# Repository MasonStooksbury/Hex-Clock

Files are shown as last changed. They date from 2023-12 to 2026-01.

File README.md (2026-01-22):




# Hex Clock | KiCad 9.0

From the mind of my good friend and inventor Johnathan Wood comes: the *Hex Clock*. A novel timepiece combining two of his favorite things: technology and hexagons. The Hex Clock uses two hexagons to represent sexigesimal, 24-hour time using two 6-bit binary numbers wrapped around hexagons. Let's see a picture that will hopefully make more sense. (And yes, the left-most bit of the hours hex will never be illuminated except during animations)

<br>

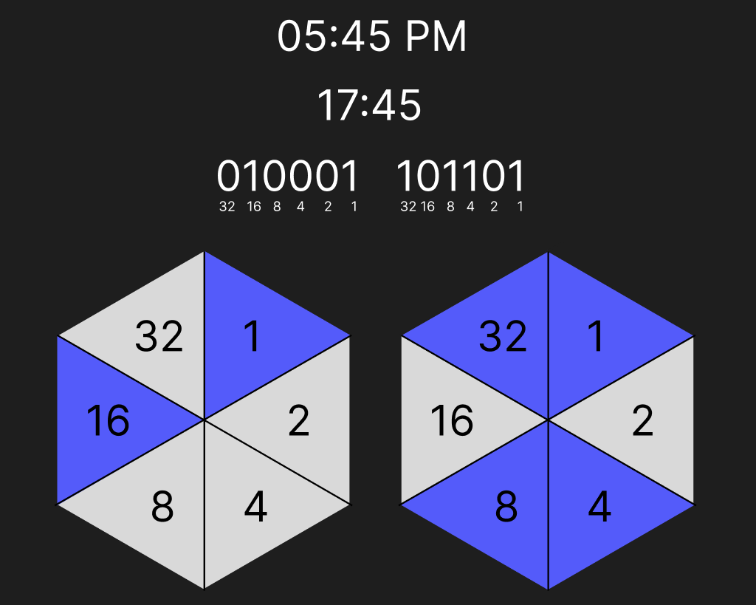
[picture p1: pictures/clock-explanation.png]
Visual description of how the clock works


<br><br><br>

# Pre-setup Instructions
### Download these things (if you don't already have them)
- Download VSCode: [link](https://code.visualstudio.com/download)
- Install VSCode Extension `MicroPico` by paulober
- Download firmware for RaspberryPi PicoW (if you haven't already done this): [latest](https://rpf.io/pico-w-firmware)
- Download/Clone the code from this repo

<br><br><br>

# Developer Setup
- Open just the `PicoWCode` folder in VSCode; it should look something like this:
  - This is really important for a later step. Doing this wrong could have weird effects or just not work
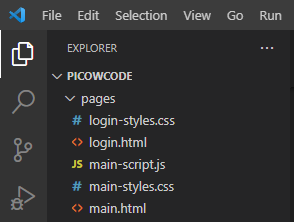
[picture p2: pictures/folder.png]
How the file explorer should look in VSCode
  - 
- Plug in your PicoW (`pico` from now on)
- Under the `View` tab, click on `Command Palette...` or do `Ctrl + Shift + P` if that shortcut is enabled
- Click `MicroPico: Connect` to attempt a connection to the pico
- Once connected, you will see options appear in the footer bar of VSCode (you'll use these mostly):
  - What the footer options look like
- If all is good, you should see that checkmark with "Pico Connected" next to it
  - If this doesn't work, try replugging it, getting a different cable, or trying a different USB port
- Finally, open up the `test.py` file and make sure that you are on that tab (when we hit the `Run` footer button, MicroPico will attempt to run whatever tab we currently have focused)
- Click the `Run` footer button
- If you see "Everything is awesome!" in the terminal, then you're ready to start developing!

<br><br><br>

# Developing and Testing
### This will put all of your code onto the pico, and allow you to start testing
- Click the `All commands` footer button
- Click `MicroPico: Upload project to Pico`. This will put all of the files in the lefthand explorer onto the pico (this is why we need to open *only* the `PicoWCode` folder in VSCode)
- Once finished, it's often good to do a soft reset (no idea why, I've just noticed it help sometimes) simply click the `Reset` footer button
- Make sure that the `main.py` (or whatever `.py` file you are currently testing) is open and focused
- Click the `Run` footer button

<br>

## Quick and Dirty Testing
### If you just want to test code in a singular file (and don't really need everything else) you can simply focus the relevant file and hit the `Run` footer button. This is particularly helpful when developing new animations or random bits of code

### NOTE: If you're trying to test a file that imports another file (and you're changing both files regularly), this won't work and you'll have to follow the above instructions where you upload the code to the pico. 
  
<br><br><br>

# Connecting to the Pico and Using the Web App
### These instructions will help you connect to the Pico with your phone or other device and use the webapp that allows you to set the clock colors, change the time, or change the login credentials
- Either plug in the pico to an external power source or - if developing with VSCode open - connect the pico, open the main.py file, and click the `Run` footer button
- Once you see the `AP is active. You can now connect` message, the pico wifi access point (AP) is ready to receive connections
- Take note of the IP address listed just below this as you will need it in a moment (NOTE: In final version, this will hopefully be replaced with a domain name that you can connect to)
- On a wifi-enabled device, look for the `Hex Clock` network and connect to it (this is the default name and can be changed in the `main.py` script if desired)
- Once connected, open your web browser and type in the IP address from the previous step into the address bar
- At this point, you should see the Hex Clock login screen
- Login with these default credentials:
  - Username: `flump`
  - Password: `doople`

<br><br><br>

# Changing the Access Point SSID
- Changing the AP SSID is as simple as changing the line towards the top of `main.py`. However, the tricky part is in getting it propagate
- The steps below are about the only sure-fire way I've found to get it to work
  - Make sure the pico isn't currently running (if it is, click the `Stop` footer button to do so)
  - Click the `All commands` footer button
  - Click the `MicroPico: Delete all files from board` option
  - Click the `Reset` footer button
  - Physically unplug the pico from the computer
  - Plug the pico back in
  - Reconnect MicroPico manually or wait a second (it's usually pretty good about reconnecting automatically)
  - Click the `All commands` footer button
  - Click the `MicroPico: Upload project to Pico` option
  - Click the `Reset` footer button
  - On your wifi-enabled device that you are going to connect, go into your wifi settings and forget the network you previously attached to (this is critical as sometimes it will not show the SSID change on your device)
  - Click the `Run` footer button
  - At this point you should see the new SSID being broadcast under the available networks

<br><br><br>

# Troubleshooting
### These are some things I've run into and how to fix them
- Every now and then when you try to run `main.py` and the AP attempts to start up you might see this error: `OSError: [Errno 98] EADDRINUSE`. Follow these steps to mitigate it
  - If running, click the `Stop` footer button
  - Click the `Reset` footer button to perform a soft reset of the pico
  - Click the `Run` footer button again
  - If the above steps do not work, you can also just try click `Run` over and over again. Usually after 3-5 attempts it will work
- Sometimes when trying to hit the `Run` footer button you will see: `SyntaxError: invalid syntax`. Typically this just means that you have the wrong script focused. Make sure you are on the `main.py` script (or whatever script you're working on)

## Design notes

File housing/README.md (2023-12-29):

- Use the STL files if you just want to print the housing
- Use the STP/STEP files if you want to *modify* the housing in Fusion360 or other CAD software

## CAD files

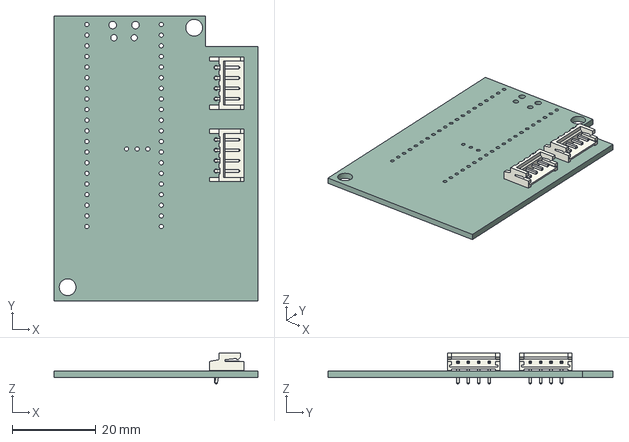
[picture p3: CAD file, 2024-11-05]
pcb/main-board/main-board.step
48.8 x 68.0 x 7.40 mm
JST_S4B_EH x 2
main-board_PCB

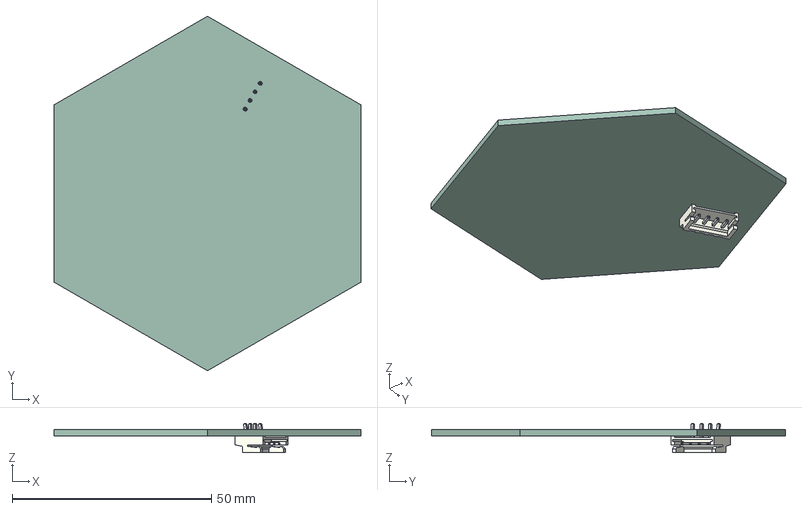
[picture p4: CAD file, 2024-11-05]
pcb/hex-board/hex-board.step
77.1 x 89.0 x 7.40 mm
JST_S4B_EH
hex-board_PCB

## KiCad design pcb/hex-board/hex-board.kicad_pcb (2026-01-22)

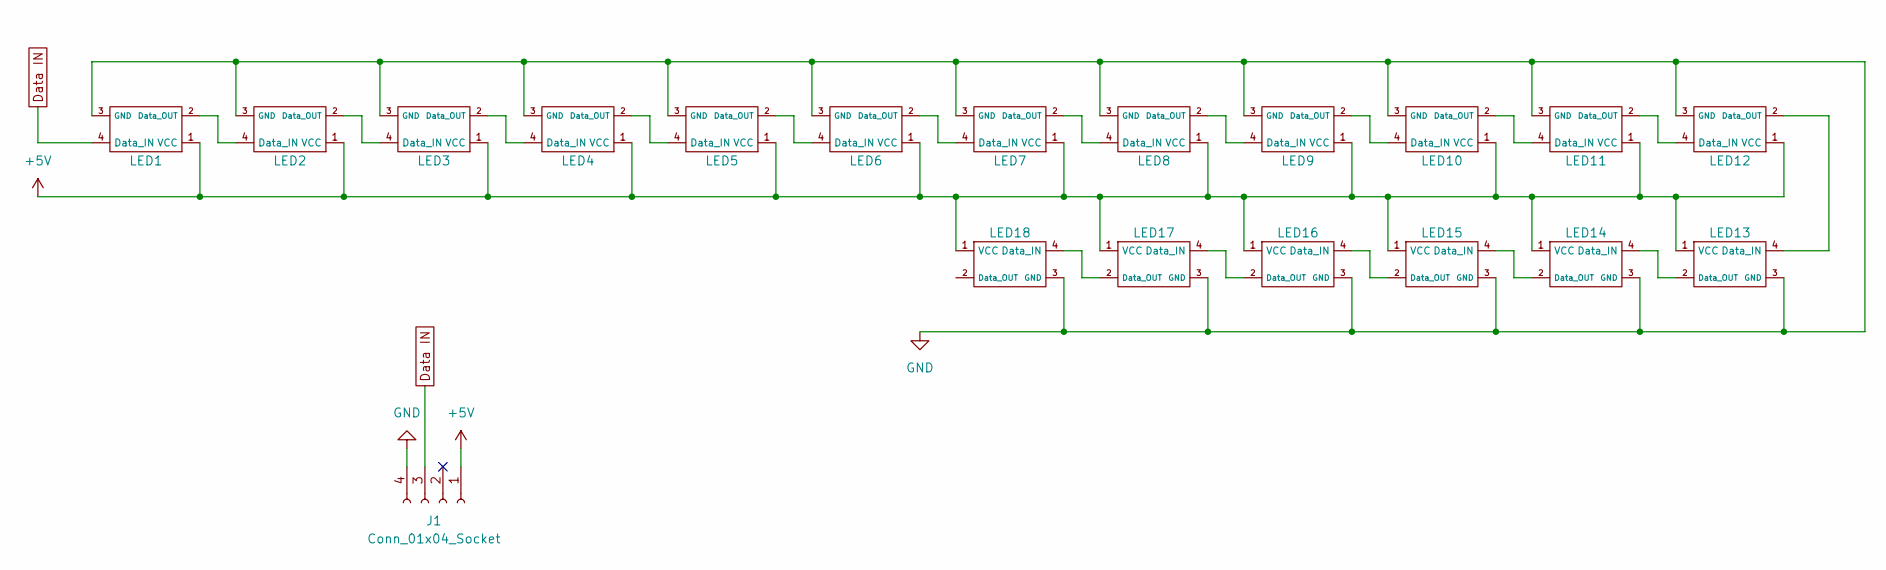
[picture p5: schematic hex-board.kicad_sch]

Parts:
J1: Conn_01x04_Socket; JST_EH_S4B-EH_1x04_P2.50mm_Horizontal
LED1, LED2, LED3, LED4, LED5, LED6, LED7, LED8, LED9, LED10, LED11, LED12, LED13, LED14, LED15, LED16, LED17, LED18: LED_SK6812RGBW_5050Metric_Pad1.5x1.5mm_HandSolder

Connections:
+5V: J1.1, LED1.1 (VCC), LED2.1 (VCC), LED3.1 (VCC), LED4.1 (VCC), LED5.1 (VCC), LED6.1 (VCC), LED7.1 (VCC), LED8.1 (VCC), LED9.1 (VCC), LED10.1 (VCC), LED11.1 (VCC), LED12.1 (VCC), LED13.1 (VCC), LED14.1 (VCC), LED15.1 (VCC), LED16.1 (VCC), LED17.1 (VCC), LED18.1 (VCC)
Data IN: J1.3, LED1.4 (Data_IN)
GND: J1.4, LED1.3 (GND), LED2.3 (GND), LED3.3 (GND), LED4.3 (GND), LED5.3 (GND), LED6.3 (GND), LED7.3 (GND), LED8.3 (GND), LED9.3 (GND), LED10.3 (GND), LED11.3 (GND), LED12.3 (GND), LED13.3 (GND), LED14.3 (GND), LED15.3 (GND), LED16.3 (GND), LED17.3 (GND), LED18.3 (GND)
unnamed: LED1.2 (Data_OUT), LED2.4 (Data_IN)
unnamed: LED2.2 (Data_OUT), LED3.4 (Data_IN)
unnamed: LED3.2 (Data_OUT), LED4.4 (Data_IN)
unnamed: LED4.2 (Data_OUT), LED5.4 (Data_IN)
unnamed: LED5.2 (Data_OUT), LED6.4 (Data_IN)
unnamed: LED6.2 (Data_OUT), LED7.4 (Data_IN)
unnamed: LED7.2 (Data_OUT), LED8.4 (Data_IN)
unnamed: LED8.2 (Data_OUT), LED9.4 (Data_IN)
unnamed: LED9.2 (Data_OUT), LED10.4 (Data_IN)
unnamed: LED10.2 (Data_OUT), LED11.4 (Data_IN)
unnamed: LED11.2 (Data_OUT), LED12.4 (Data_IN)
unnamed: LED12.2 (Data_OUT), LED13.4 (Data_IN)
unnamed: LED13.2 (Data_OUT), LED14.4 (Data_IN)
unnamed: LED14.2 (Data_OUT), LED15.4 (Data_IN)
unnamed: LED15.2 (Data_OUT), LED16.4 (Data_IN)
unnamed: LED16.2 (Data_OUT), LED17.4 (Data_IN)
unnamed: LED17.2 (Data_OUT), LED18.4 (Data_IN)

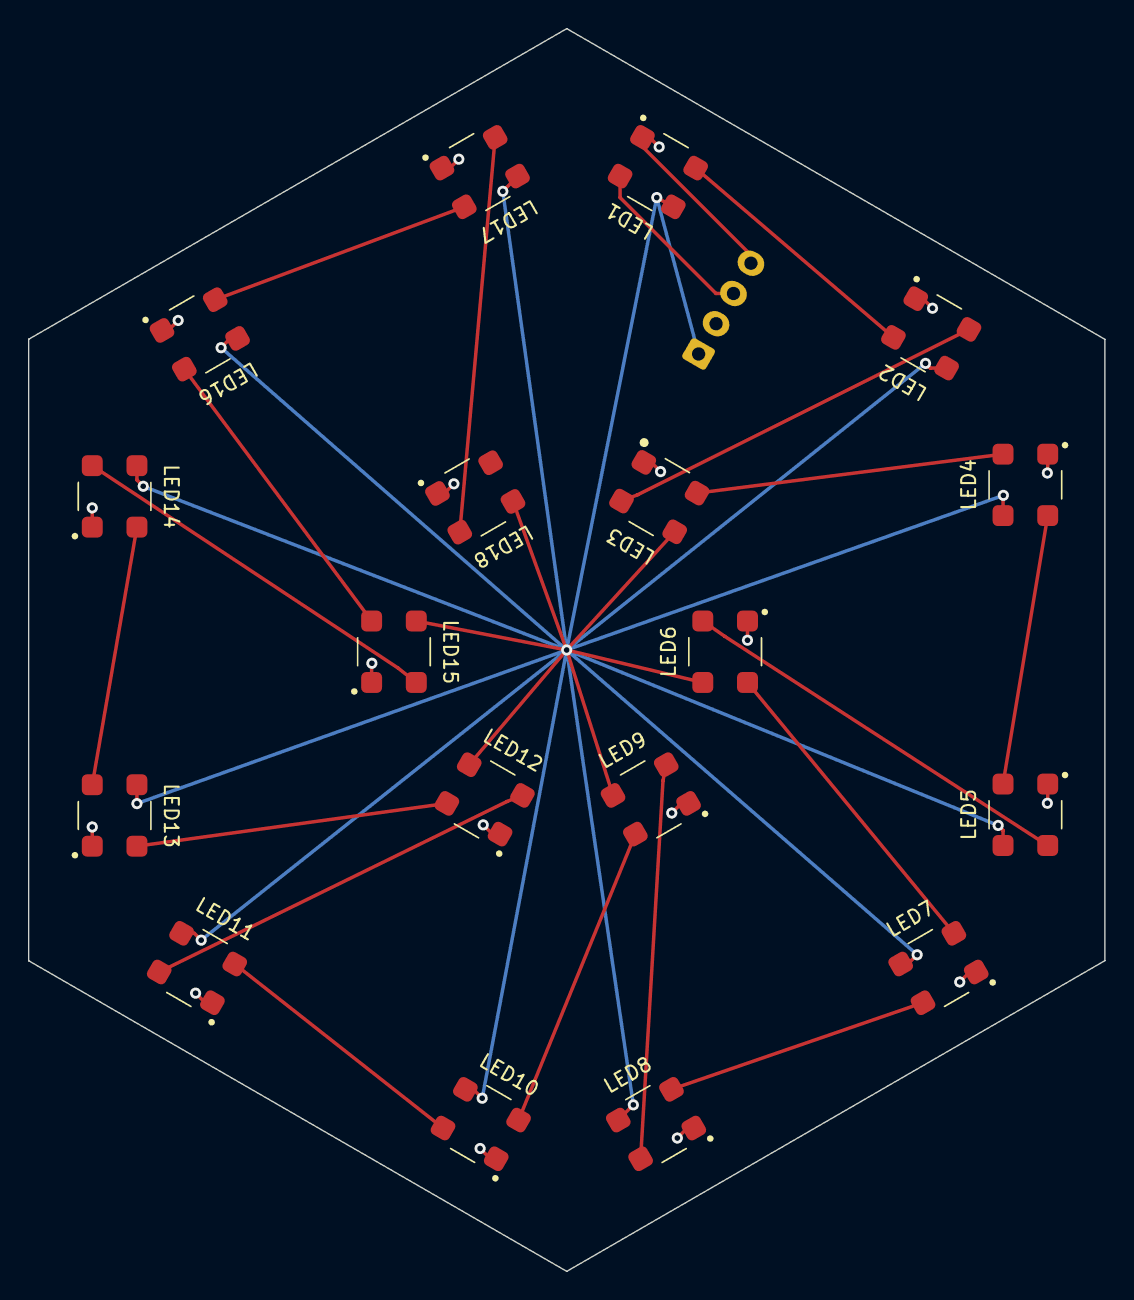
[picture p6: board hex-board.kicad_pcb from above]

Board: 2 copper layers, 77.1 x 89.0 mm, 19 parts (1 on the bottom side), 20 nets.

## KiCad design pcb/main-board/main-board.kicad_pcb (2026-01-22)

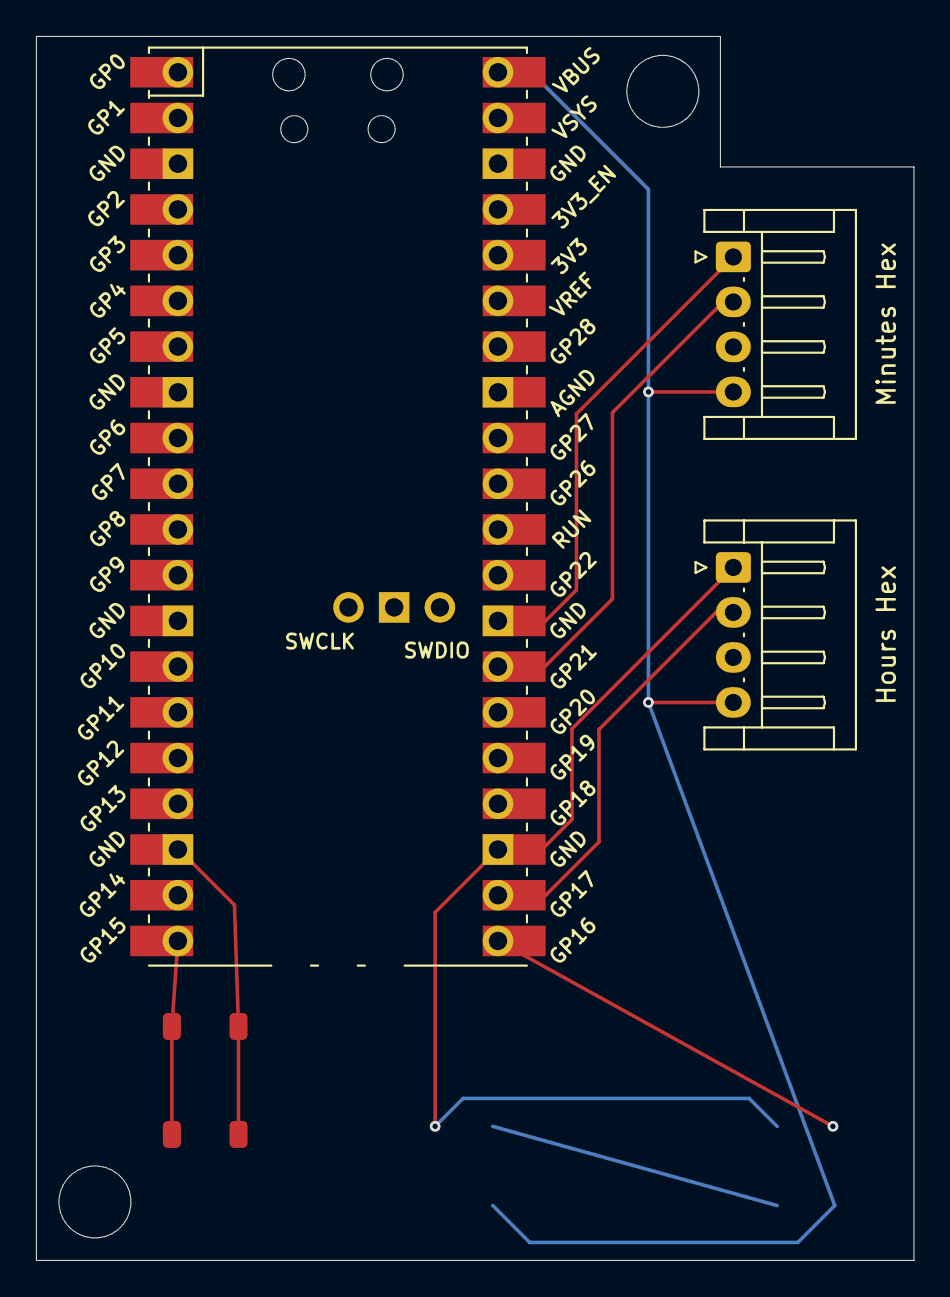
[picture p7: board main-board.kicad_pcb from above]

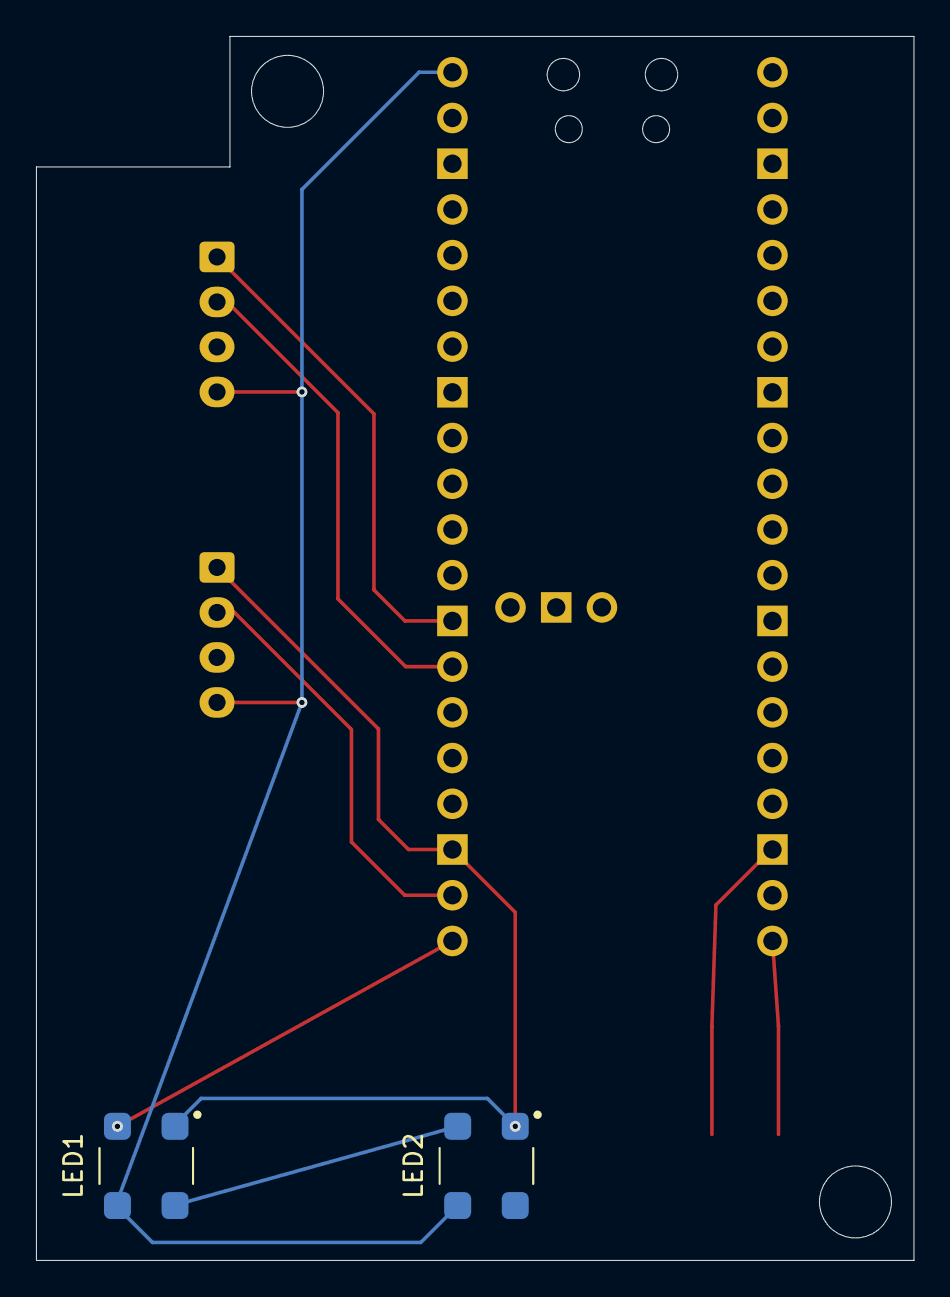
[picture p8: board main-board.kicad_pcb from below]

Board: 2 copper layers, 48.8 x 68.0 mm, 6 parts (2 on the bottom side), 9 nets.

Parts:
Hours Hex: Conn_01x04_Socket; JST_EH_S4B-EH_1x04_P2.50mm_Horizontal
LED1, LED2: LED_SK6812RGBW_5050Metric_Pad1.5x1.5mm_HandSolder
Minutes Hex: Conn_01x04_Socket; JST_EH_S4B-EH_1x04_P2.50mm_Horizontal
SW1: SW_Push; Switch
U1: PicoW; RPi_PicoW_SMD_TH

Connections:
unnamed: Minutes Hex.1, U1.28 (GND)
unnamed: Minutes Hex.2, U1.27 (GPIO21)
unnamed: Hours Hex.4, LED1.1 (VCC), LED2.1 (VCC), Minutes Hex.4, U1.40 (VBUS)
unnamed: Hours Hex.1, LED1.3 (GND), LED2.3 (GND), U1.23 (GND)
unnamed: Hours Hex.2, U1.22 (GPIO17)
unnamed: LED1.4 (Data_IN), U1.21 (GPIO16)
unnamed: LED1.2 (Data_OUT), LED2.4 (Data_IN)
unnamed: SW1.2, U1.18 (GND)
unnamed: SW1.1, U1.20 (GPIO15)

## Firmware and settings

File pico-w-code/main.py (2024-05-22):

import json, re, network, socket, machine, gc
from time import sleep
import utils

# Highly recommended to set a lowish garbage collection threshold to minimise memory fragmentation as we sometimes want to
#       allocate relatively large blocks of RAM
gc.threshold(50000)

PAGES_PATH = "pages"
CONFIG_FILE_PATH = 'config.json'
IS_AUTHENTICATED = False

login_error_status = 'none'

# Returns the desired values from the config file as a dictionary
def getValuesFromConfig(*args):
    with open(CONFIG_FILE_PATH, 'r') as file:
        data = json.load(file)

    # Create an object composed of the desired keys from the config file
    results = {}    
    for key in args:
        results[key] = data.get(key)

    return results



# Updates the specified keys in the config file with their new values
# Can't do the fancy truncate hack since Micropython doesn't have truncate() at time of writing
def updateValuesInConfig(**kwargs):
    data = ''
    # Read file contents into variable for editing
    with open(CONFIG_FILE_PATH, "r") as f:
        data = json.load(f)

    # Augment the keys with new values
    data.update(**kwargs)

    # Write the new contents to the file
    with open(CONFIG_FILE_PATH, 'w') as f:
        try:
            json.dump(data, f)
            print('Values in config file have been successfully updated')
            return True
        except:
            return False



# Sends a page to the client ("renders" it). Will augment it with any passed-in kwargs where applicable
def render(filepath, **kwargs):
    file_requested = ''
    # Read the passed-in file to a variable
    with open(filepath, 'r') as file:
        file_requested = file.read()
    # If kwargs have been passed in, augment the file to include them
    if kwargs:
        pattern = r"~~(\w+)~~"

        # Use a lambda function for replacement
        return re.sub(pattern, lambda m: kwargs.get(m.group(1), m.group(0)), file_requested)
    return file_requested



##############################################
################## PAGES #####################
##############################################
# These methods return various things to the client when requested. The reason these are in separate methods is to 
#       allow for more logic once we start integrating the clock (or we want to add other stuff)
def mainStyles():
    return render(f'{PAGES_PATH}/main-styles.css')

def mainJavascript():
    # TODO: Need to add "Content-Type: text/javascript" to a header somewhere
    return render(f'{PAGES_PATH}/main-script.js', **getValuesFromConfig('time', 'off_color', 'on_color', 'colon_color'))

def loginStyles():
    return render(f'{PAGES_PATH}/login-styles.css')

def index():
    return render(f'{PAGES_PATH}/login.html', errorStatus = login_error_status)

def main():
    return render(f'{PAGES_PATH}/main.html')
##############################################
##############################################
##############################################


# Setup a custom AP
ap = network.WLAN(network.AP_IF)
# Create an open AP (i.e. no password needed to connect)
ap.config(essid=getValuesFromConfig('ap_ssid')['ap_ssid'], security=0)



# Activate the AP and respond to routes
def activateAP():
    global IS_AUTHENTICATED
    global login_error_status

    # Available routes the AP will respond to
    # It's important to make these callbacks and not function calls because - while it will still work - it saves the render in this dictionary and never calls it again
    #       This means that if a page updates, we never call render() again (because we never call these functions again)
    #       Making these callbacks makes it so that we actually call each function every time
    routes = {
        '/': index,
        '/main': main,
        '/login-styles.css': loginStyles,
        '/main-styles.css': mainStyles,
        '/main-script.js': mainJavascript,
        '/leave': '' # We don't need anything here because the loop breaks before we try and hit this. But the entry still needs to be here
    }

    # Activate AP
    ap.active(True)

    # Wait till it's active before we do anything
    while ap.active() == False:
        pass
    print('AP is active. You can now connect')
    print('IP address to connect to: ' + ap.ifconfig()[0])

    # Once active, listen for connections
    s = socket.socket(socket.AF_INET, socket.SOCK_STREAM)
    # This helps with this error: OSError: [Errno 98] EADDRINUSE
    # TODO: Very rarely you will get this error anyway. Add some retry logic to do this a few times if it fails
    s.setsockopt(socket.SOL_SOCKET, socket.SO_REUSEADDR, 1)
    s.bind(('', 80))
    s.listen(5) # Allows 5 connections. We could change this, but 5 is fine for now

    # Connection loop (wait around, accept connections, respond to appropriate routes with the right content, etc)
    while True:
        # Accept the connection
        conn, _ = s.accept()
        # print('Got a connection from: %s' % str(addr))

        # Get the request it sent
        request = conn.recv(1024)
        print('request', request)

        # print('Content = %s' % str(request))

        # Rare, but does happen from time to time (never found out why)    
        if request == b'':
            conn.close()
            continue

        # Decode our request string and only get the route
        # Looks like: "GET /index HTTP/1.1 ......"
        # Will save route as: /index
        route = request.decode().split()[1]


        if route == '/main':
            # Only respond if the username/password are in the request
            if IS_AUTHENTICATED or 'username' in request and 'password' in request:
                # But, in the case this is from a bad actor that doesn't know the scheme, route them back to the login
                #       Otherwise, the unpacking that happens will break and halt the AP
                try:
                    # Get the username/password that was attached to the request
                    username, password = request.decode().split('\r\n')[-1].split('&')
                    username = username.split('=')[-1]
                    password = password.split('=')[-1]

                    # Get the username/password from our config file
                    credentials = getValuesFromConfig('username', 'password')

                    # If username/password matches the config file, let them in
                    if username == credentials['username'] and password == credentials['password']:
                        IS_AUTHENTICATED = True
                        login_error_status = 'none'
                    # Otherwise, set the error block on the login page and change the route back to the login
                    else:
                        route = '/'
                        login_error_status = 'block'
                except:
                    route = '/'
            else:
                print('username/password not in request')

        # Change the login credentials
        elif route == '/change-login':
            # Only let them do this if they're authenticated
            if IS_AUTHENTICATED:
                print('change login request')
                # Get the username/password that was attached to the request
                new_username, new_password = request.decode().split('\r\n')[-1].split('&')

                # Save these values to the config file so they can be read later
                updateValuesInConfig(username = new_username.split('=')[-1], password = new_password.split('=')[-1])

                # Take them to /main. This will trigger a re-render
                route = '/main'

        # Change the time (both in the web so it shows the correct time and on the clock itself)
        elif route == '/change-time':
            # Only let them do this if they're authenticated
            if IS_AUTHENTICATED:
                print('change time request')
                new_time = request.decode().split('\r\n')[-1]
                # At this point, new_time looks like this: time=08%3A32
                # This line will convert it to this: 08:32
                new_time = ':'.join(new_time.split('=')[-1].split('%3A'))
                updateValuesInConfig(time = new_time)
                updateDatetime()
                # TODO: Change the time on the clock here
                route = '/main'

        # Change the date
        elif route == '/change-date':
            # Only let them do this if they're authenticated
            if IS_AUTHENTICATED:
                print('change date request')
                new_date = request.decode().split('\r\n')[-1]
                new_date = new_date.split('=')[-1]
                updateValuesInConfig(date = new_date)
                updateDatetime()
                route = '/main'

        # When they exit the webpage
        # This will break out of our while loop and hit our outer function to shutdown the AP and run the clock code
        elif route == '/leave':
            # Only let them do this if they're authenticated
            if IS_AUTHENTICATED:
                print('in leave')
                updateValuesInConfig(start_ap = 'False')
                break


        # Only respond to routes that are specified
        if route == '' or route == b'' or route is None or route not in routes.keys():
            conn.close()
            continue

        # Don't let them get anything for the main page unless they're authenticated
        if route == '/main-styles.css' or route == '/main-script.js':
            if not IS_AUTHENTICATED:
                print('not authenticated')
                conn.close()
                continue

        print(route)
        # Send the connected thing the appropriate page for the route they requested
        conn.sendall(routes[route]())

        # Counter-intuitively, this has to be here to make things work
        conn.close()

        gc.collect()



# Shutdown the AP and do some garbage collection
def deactivateAP():
    global IS_AUTHENTICATED
    IS_AUTHENTICATED = False
    ap.active(False)
    gc.collect()



# Return the numeric day of the week by calculating it
def getDowFromDate(date):
    month_keys = (1,4,4,0,2,5,0,3,6,1,4,6)
    days_of_week = ("Saturday", "Sunday", "Monday", "Tuesday", "Wednesday", "Thursday", "Friday")
    [yyyy, mm, dd] = [int(i) for i in date.split('T')[0].split('-')]
    leap_year_modifier = 0
    if ((yyyy % 400 == 0) or (yyyy % 100 != 0) and (yyyy % 4 == 0)) and mm in (1, 2):
        leap_year_modifier = -1
    a = yyyy % 100
    b = a // 4
    year_modifier = 0
    if yyyy < 1800:
        year_modifier = 4
    elif 1799 < yyyy < 1900:
        year_modifier = 2
    elif 1999 < yyyy < 2100:
        year_modifier = -1
    day = (a + b + dd + month_keys[mm-1] + leap_year_modifier + year_modifier) % 7

    reorganized_days = ['Monday', 'Tuesday', 'Wednesday', 'Thursday', 'Friday', 'Saturday', 'Sunday']
    current_day = days_of_week[day]

    count = 0
    for day in reorganized_days:
        if current_day == day:
            break
        count += 1
    return count



# Update the RTC datetime by pulling values from the config file 
def updateDatetime():
    values = getValuesFromConfig('date', 'time')
    date_pieces = [int(x) for x in values['date'].split('-')]
    time_pieces = [int(x) for x in values['time'].split(':')]

    day_of_week = getDowFromDate(f"{values['date']}T{time_pieces[0]}:{time_pieces[1]}:00")

    rtc.datetime((date_pieces[0], date_pieces[1], date_pieces[2], day_of_week, time_pieces[0], time_pieces[1], 0, 0))

    print('RTC datetime has been updated')



# This will run whatever clock code we have (W.I.P.)
def runClockCode():
    while True:
        # Check for interrupts here so we can break?
        print('hello')
        print(getValuesFromConfig('time')['time'])
        print(rtc.datetime())
        sleep(15)
    # TODO: If we do break, clean up
    gc.collect()






# Initialize the RTC and make an accessor
rtc = machine.RTC()


# Main loop
while True:
    # Start AP until we need to shut it down
    if getValuesFromConfig('start_ap')['start_ap'] == 'True':
        activateAP()
        # deactivateAP()
    # Otherwise run clock code
    else:
        print('run clock code')
        runClockCode()

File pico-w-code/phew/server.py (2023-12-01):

import uasyncio, os, time
from . import logging

_routes = []
catchall_handler = None
loop = uasyncio.get_event_loop()


def file_exists(filename):
  try:
    return (os.stat(filename)[0] & 0x4000) == 0
  except OSError:
    return False


def urldecode(text):
  text = text.replace("+", " ")
  result = ""
  token_caret = 0
  # decode any % encoded characters
  while True:
    start = text.find("%", token_caret)
    if start == -1:
      result += text[token_caret:]
      break
    result += text[token_caret:start]
    code = int(text[start + 1:start + 3], 16)
    result += chr(code)
    token_caret = start + 3
  return result

def _parse_query_string(query_string):
  result = {}
  for parameter in query_string.split("&"):
    print('in parse query string')
    key, value = parameter.split("=", 1)
    print('after unpack PQS')
    key = urldecode(key)
    value = urldecode(value)
    result[key] = value
  return result


class Request:
  def __init__(self, method, uri, protocol):
    self.method = method
    self.uri = uri
    self.protocol = protocol
    self.form = {}
    self.data = {}
    self.query = {}
    query_string_start = uri.find("?") if uri.find("?") != -1 else len(uri)
    self.path = uri[:query_string_start]
    self.query_string = uri[query_string_start + 1:]
    if self.query_string:
      self.query = _parse_query_string(self.query_string)

  def __str__(self):
    return f"""\
request: {self.method} {self.path} {self.protocol}
headers: {self.headers}
form: {self.form}
data: {self.data}"""


class Response:
  def __init__(self, body, status=200, headers={}):
    self.status = status
    self.headers = headers
    self.body = body

  def add_header(self, name, value):
    self.headers[name] = value

  def __str__(self):
    return f"""\
status: {self.status}
headers: {self.headers}
body: {self.body}"""


content_type_map = {
  "html": "text/html",
  "jpg": "image/jpeg",
  "jpeg": "image/jpeg",
  "svg": "image/svg+xml",
  "json": "application/json",
  "png": "image/png",
  "css": "text/css",
  "js": "text/javascript",
  "csv": "text/csv",
}


class FileResponse(Response):
  def __init__(self, file, status=200, headers={}):
    self.status = 404
    self.headers = headers
    self.file = file

    try:
      if (os.stat(self.file)[0] & 0x4000) == 0:
        self.status = 200

        # auto set content type
        extension = self.file.split(".")[-1].lower()
        if extension in content_type_map:
          headers["Content-Type"] = content_type_map[extension]

        headers["Content-Length"] = os.stat(self.file)[6]
    except OSError:
      return False


class Route:
  def __init__(self, path, handler, methods=["GET"]):
    self.path = path
    self.methods = methods
    self.handler = handler
    self.path_parts = path.split("/")

  # returns True if the supplied request matches this route
  def matches(self, request):
    if request.method not in self.methods:
      return False
    compare_parts = request.path.split("/")
    if len(compare_parts) != len(self.path_parts):
      return False
    print('in route class matches')
    for part, compare in zip(self.path_parts, compare_parts):
      if not part.startswith("<") and part != compare:
        return False
    print('after route class matches unpack')
    return True

  # call the route handler passing any named parameters in the path
  def call_handler(self, request):
    parameters = {}
    print('in route class call_handler')   
    for part, compare in zip(self.path_parts, request.path.split("/")):
      if part.startswith("<"):
        name = part[1:-1]
        parameters[name] = compare
    print('after route class call_handler unpack')
    return self.handler(request, **parameters)
        
  def __str__(self):
    return f"""\
path: {self.path}
methods: {self.methods}
"""

  def __repr__(self):
    return f"<Route object {self.path} ({', '.join(self.methods)})>"


# parses the headers for a http request (or the headers attached to
# each field in a multipart/form-data)
async def _parse_headers(reader):
  headers = {}
  while True:
    header_line = await reader.readline()
    # CRLF denotes body start
    if header_line == b"\r\n" or header_line == b'':
      break
    # This should capture any weird nonsense that I noticed during testing
    if ': ' not in header_line:
      continue
    name, value = header_line.decode().strip().split(": ", 1)
    headers[name.lower()] = value
  return headers


# returns the route matching the supplied path or None
def _match_route(request):
  for route in _routes:
    if route.matches(request):
      return route
  return None


# if the content type is multipart/form-data then parse the fields
async def _parse_form_data(reader, headers):
  print('in parse form data')
  boundary = headers["content-type"].split("boundary=")[1]
  # discard first boundary line
  dummy = await reader.readline()

  form = {}
  while True:
    # get the field name
    print('before headers')
    field_headers = await _parse_headers(reader)
    print('after headers')
    if len(field_headers) == 0:
      break
    name = field_headers["content-disposition"].split("name=\"")[1][:-1]
    # get the field value
    value = ""
    while True:
      line = await reader.readline()
      line = line.decode().strip()
      # if we hit a boundary then save the value and move to next field
      if line == "--" + boundary:
        form[name] = value
        break
      # if we hit end of form data boundary then save value and return
      if line == "--" + boundary + "--":
        form[name] = value
        return form
      value += line
  return None


# if the content type is application/json then parse the body
async def _parse_json_body(reader, headers):
  import json
  content_length_bytes = int(headers["content-length"])
  body = await reader.readexactly(content_length_bytes)
  return json.loads(body.decode())


status_message_map = {
  200: "OK", 201: "Created", 202: "Accepted", 
  203: "Non-Authoritative Information", 204: "No Content",
  205: "Reset Content", 206: "Partial Content", 300: "Multiple Choices",
  301: "Moved Permanently", 302: "Found", 303: "See Other",
  304: "Not Modified", 305: "Use Proxy", 306: "Switch Proxy",
  307: "Temporary Redirect", 308: "Permanent Redirect",
  400: "Bad Request", 401: "Unauthorized", 403: "Forbidden",
  404: "Not Found", 405: "Method Not Allowed", 406: "Not Acceptable",
  408: "Request Timeout", 409: "Conflict", 410: "Gone",
  414: "URI Too Long", 415: "Unsupported Media Type", 
  416: "Range Not Satisfiable", 418: "I'm a teapot",
  500: "Internal Server Error", 501: "Not Implemented"
}
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

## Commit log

2023-11-19 Renaming files
    [Hex-Clock.csv, Hex-Clock.kicad_pcb, Hex-Clock.kicad_sch]
2023-11-19 Added pads for DATA_IN and 5V
    [Hex-Clock.kicad_pcb]
2023-11-21 Added ground pad
    [Hex-Clock.kicad_pcb]
2023-11-26 Moving PCB stuff and adding PicoW code
    [Hex-Clock.csv, Hex-Clock.kicad_pcb, Hex-Clock.kicad_sch]
2023-11-27 Wired up hexes and got all screens sending back relevant info to the main Python script
2023-11-27 Added toggle button to show current time. Got it all wired up to show correct colors when switching between current and preview time. Also added a dropdown with options for preset colors. Need to wir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
2023-12-01 Modified code so that there are fewer file reads. Fixed the short-write sending for page serving. And commented everything
    [main.py]
2023-12-02 Added lots of code to get everything wired and working. Mostly the login page and security around the routing
2023-12-02 Moved password stuff around, AP starts without password, added entry/exit logic for AP mode. Code now starts in one mode and can switch to the other when you leave. Cleaned up some code, added commen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
2023-12-06 Started adding LED code now that PCB is in and prepped
2023-12-15 Added necessary code to display a binary number on the PCB with a particular color. Also added comments to everything to be a bit more clear, as well as solved a bug in the animation code that was ca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
    [main.py]
2023-12-29 Added housing folder for when we do 3D stuff
2024-01-02 Added LambBrainz silkscreen logo. Added alignment dot for LEDs on silkscreen. Modified some traces
    [Hex-Clock.kicad_pcb]
2024-07-05 Moved everything around, renamed a bunch of stuff, started on the Main Board, and updated to KiCad 8
    [Hex-Clock.csv, Hex-Clock.kicad_pcb, Hex-Clock.kicad_sch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]
2024-07-05 Mostly finished main board, just need to add a password reset switch
    [main-board.kicad_pcb, main-board.kicad_sch]
2024-07-05 Fixing folder name case sensitivity issue
    [hex-board.kicad_pcb, hex-board.kicad_sch, main-board.kicad_pcb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]
2024-07-05 Added switch
    [main-board.kicad_pcb, main-board.kicad_sch]
2024-07-06 Finished switch placement and wiring
    [main-board.kicad_pcb]
2024-07-07 Added JST connector to hex board
    [hex-board.kicad_pcb, hex-board.kicad_sch, main-board.kicad_pcb]
2024-07-07 Added colon LEDs, moved stuff around the board, etc
    [main-board.kicad_pcb, main-board.kicad_sch]
2024-07-09 Added more space around mounting hole, added labels to JST connectors again
    [main-board.kicad_pcb]
2026-01-22 Updating to 9.0
    [hex-board.kicad_pcb, hex-board.kicad_sch, main-board.kicad_pcb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]

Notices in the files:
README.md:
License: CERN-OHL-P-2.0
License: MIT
